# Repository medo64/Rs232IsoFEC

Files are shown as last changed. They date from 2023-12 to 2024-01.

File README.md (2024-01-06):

[Isolated RS-232 Framework Expansion Card](https://medo64.com/rs232isofec/)
===========================================================================

This Framework laptop expansion card will show up on your system as a serial
device and allow for isolated RS-232 communication up to 460,800 baud rate.

## UART Pinout

To connect to this board, one has to use a 5-pin JST XH connector. The following
table represents the pinout, pin 1 being on the left as looking into the
expansion card. Note that pins 1 and 5 are not internally connected.

| # | Ref | Description | DB9 |
|--:|:---:|---|----:|
| 1 |  -  | Not connected |  8  |
| 2 | RXD | Receive data |  2  |
| 3 | GND | Ground connection |  5  |
| 4 | TXD | Transmit data |  3  |
| 5 |  -  | Not connected |  7  |

As power consumption is low, wires can be almost any AWG. I would recommend
using 24 AWG wire 0.25 mm² as they allow for greater compatibility with other
connectors.

## Supported Speeds

This board employs the FT232R as its UART chip, and consequently, it supports
all the baud rates this chip [can handle](https://ftdichip.com/Documents/AppNotes/AN232B-05_BaudRates.pdf)
up to 460,800 baud which is the limit of isolator chip used. The table below
lists the standard baud rates.

| Baud rate | Actual | Error | Divisor |
|---:|---:|---:|---:|
| 300 | 300 | 0.00% |  10000.000 |
| 600 | 600 | 0.00% | 5000.000 |
| 1,200 | 1,200 | 0.00% | 2500.000 |
| 1,800 | 1,800 | 0.00% | 1666.625 |
| 2,400 | 2,400 | 0.00% | 1250.000 |
| 4,800 | 4,800 | 0.00% | 625.000 |
| 7,200 | 7,201 | 0.01% | 416.625 |
| 9,600 | 9,600 | 0.00% | 312.500 |
| 14,400 | 14,406 | 0.04% | 208.250 |
| 19,200 | 19,200 | 0.00% | 156.250 |
| 28,800 | 28,812 | 0.04% | 104.125 |
| 38,400 | 38,400 | 0.00% | 78.125 |
| 57,600 | 57,692 | 0.16% | 52.000 |
| 115,200 | 115,385 | 0.16% | 26.000 |
| 230,400 | 230,769 | 0.16% | 13.000 |
| 460,800 | 461,538 | 0.16% | 6.500 |

While rates above this can be set, they are not guaranteed to work.

---
*You can check my blog and other projects at [www.medo64.com](https://www.medo64.com/electronics/).*

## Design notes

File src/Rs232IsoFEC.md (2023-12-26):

### Rs232IsoFEC Parts

|  # | Part | RefDes  | Preferred Part Number |
|---:|---|---|---|
|  1 | C 10nF X7R 16V (0805) | C1 | 399-17617-1-ND |
|  9 | C 100nF X7R 16V (0805) | C2-C10  | 478-5311-1-ND |
|  1 | C 4.7uF X5R 16V (0805) | C11 | 1276-1244-1-ND |
|  1 | D TVS 12V PESD12VL2BT (SOT23-3) | D1 | 1727-3809-1-ND |
|  2 | DS LED (0805) | DS1-DS2 | 475-1415-1-ND |
|  1 | J JST XH Vertical (3w) | J1 | 455-2248-ND |
|  1 | L Ferrite 600R@100Mhz | L1 | 240-2390-1-ND |
|  1 | P USB C, plug, straddle 0.8mm | P1 | WM12855-ND |
|  1 | Q P-MOSFET DMP3099L-13 (SOT23) | Q1 | DMP3099L-13DICT-ND |
|  3 | R 1K 0.125W (0805) | R1-R3 | RMCF0805FT1K00CT-ND |
|  1 | R 5.1K 0.125W (0805) | R4 | RMCF0805FT5K10CT-ND |
|  1 | R 10K 0.125W (0805) | R5 | RMCF0805FT10K0CT-ND |
|  1 | U Transciever Uart FT232R (SSOP-28) | U1 | 768-FT232RNL-TUBE-ND |
|  1 | U Transciever RS232 ADM3251E (SOIC-20) | U2 | 505-ADM3251EARWZ-ND |
|  2 | H Screw M2x3mm | - | - |

#### Board Size

| | Dimensions | Area | Thickness |
|---|---|---|---|
| PCB |  24.0 x 27.9 mm | 1.1 in² | 0.8 mm |

#### FTDI Configuration

| Setting | Value  |
|---|---|
| CBUS0 | TXLED# |
| CBUS1 | RXLED# |
| CBUS2 | TXDEN  |
| CBUS3 | PWREN# |
| CBUS4 | SLEEP# |

#### Power

| Property | Value  |
|---|---:|
| Voltage  | 5 V |
| Current  | 210 mA |

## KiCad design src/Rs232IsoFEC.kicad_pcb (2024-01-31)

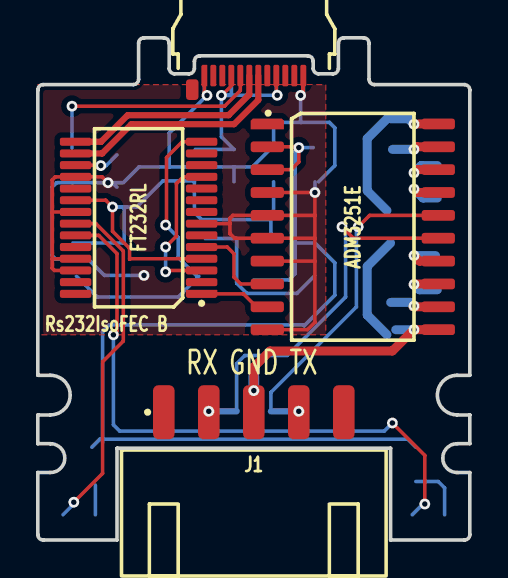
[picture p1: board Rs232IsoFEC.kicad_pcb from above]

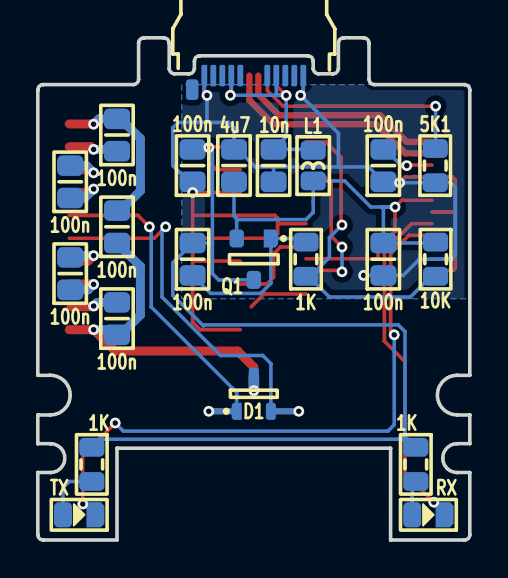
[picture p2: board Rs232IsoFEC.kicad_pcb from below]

Board: 2 copper layers, 24.0 x 27.9 mm, 25 parts (21 on the bottom side), 27 nets.

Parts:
C1: 10n; C (0805)
C2, C3, C4, C5, C6, C7, C8, C9, C10: 100n; C (0805)
C11: 4u7; C (0805)
D1: PESD12VL2BT; D TVS SM05T1G (SOT23-3)
DS1: RX; DS (0805)
DS2: TX; DS (0805)
J1: B5B-XH-A; J JST XH Edge [UART] (5w)
L1: 600R; L (0805)
P1: 105444-0001; P USB C 3.2 Edge (24w)
Q1: DMP3099L-13; Q MOSFET-P (SOT23-3)
R1, R2, R3: 1K; R (0805)
R4: 5K1; R (0805)
R5: 10K; R (0805)
U1: FT232RL; U Transciever UART FT232RL (SSOP-28)
U2: ADM3251E; U Transciever RS232 Isolated ADM3251E (SOIC-20)

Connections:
3V3: C3.2, U1.17
5V: C2.2, C11.2, L1.1, Q1.2, R5.1, U1.4, U1.20
5V_SW: C4.2, C10.2, Q1.3, R1.1, R2.1, U2.2, U2.3
A_CC: P1.A5, R4.2
GND: C1.1, C2.1, C3.1, C4.1, C11.1, P1.A1, P1.A12, P1.B01, P1.B12, R4.1, U1.7, U1.18, U1.21, U1.25, U1.26, U2.4, U2.5, U2.6, U2.7, U2.10
ISO_C1+: C6.2, U2.18
ISO_C1-: C6.1, U2.17
ISO_C2+: C8.2, U2.14
ISO_C2-: C8.1, U2.13
ISO_GND: C7.1, C9.1, D1.3, J1.3, U2.11
ISO_RXD: D1.2, J1.2, U2.15
ISO_TXD: D1.1, J1.4, U2.16
ISO_V+: C5.1, U2.19
ISO_V-: C9.2, U2.12
ISO_Viso: C5.2, C7.2, U2.20
LED_RXD: DS1.1, U1.22
LED_RXD': DS1.2, R1.2
LED_TXD: DS2.1, U1.23
LED_TXD': DS2.2, R2.2
PWREN#: R3.1, R5.2, U1.14
PWREN#': C10.1, Q1.1, R3.2
RTS_CTS: U1.3, U1.11
RXD: U1.5, U2.8
TXD: U1.1, U2.9
USB_DM: P1.A7, U1.16
USB_DP: P1.A6, U1.15
USB_Vin: C1.2, L1.2, P1.A4, P1.A9, P1.B04, P1.B09

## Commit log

2023-11-02 Added mosfet to turn off isolator in sleep mode
    [Rs232IsoFEC.kicad_pcb]
2023-11-03 Added soft-start capacitor for isolator
    [Rs232IsoFEC.kicad_pcb]
2023-11-03 Updated protection diode to 12V
    [Rs232IsoFEC.kicad_pcb]
2023-11-04 Added RTS/CTS loopback
    [Rs232IsoFEC.kicad_pcb]
2023-11-13 Changed protection diode
    [Rs232IsoFEC.kicad_pcb]
2023-11-13 Minor refactoring
    [Rs232IsoFEC.kicad_pcb]
2023-11-13 Moved LEDs to bottom
    [Rs232IsoFEC.kicad_pcb]
2023-12-26 Added PWREN pullup and moved LED 5V to switched
    [Rs232IsoFEC.kicad_pcb]
2023-12-26 Changed conntector to 5-pin variant
    [Rs232IsoFEC.kicad_pcb]
2023-12-30 Refactoring copper pour
    [Rs232IsoFEC.kicad_pcb]
2024-01-31 Moved board RefDes to top
    [Rs232IsoFEC.kicad_pcb]
